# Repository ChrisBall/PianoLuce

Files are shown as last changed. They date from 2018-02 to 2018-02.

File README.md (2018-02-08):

# PianoLuce

PianoLuce is a keypress detector for pianos, based on the Arduino platform. This project is on hiatus, having achieved it's main aim, but others trying to achieve similar results may find these resources useful.

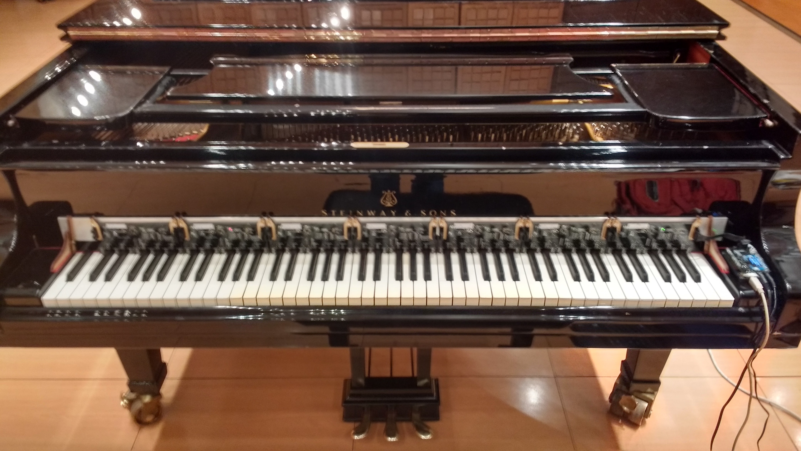
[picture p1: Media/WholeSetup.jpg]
PianoLuce in use


This project took inspiration from the development on the [Magnetic Resonator Piano](http://www.eecs.qmul.ac.uk/~andrewm/mrp.html) and similar, commercial keypress detectors like the Moog Piano Bar.

Most of the development was in aid of a performance by Marta Mołodyńska-Wheeler in June 2017, where live visuals were generated from her PhD performance of Scriabin's 24 preludes. The vision of the project was to re-create a modern day version of [Clavier à lumières](https://en.wikipedia.org/wiki/Clavier_%C3%A0_lumi%C3%A8res) by creating a non-intrusive device which could be attached to an expensive piano and create colored visuals.  Alex (Marta's husband), CEO of the IOT company [Kolomolo](www.kolomolo.com), connected with me during his research and commissioned the work.

My special thanks to: [Alex & Marta](http://www.martamolo.com/), for their time, patience, and escape rooms; to [James Medd](http://jamesmedd.co.uk/) for his assistance designing a mounting system, and coming up with the name, PianoLuce; and to [Alexander Lang](http://langster1980.blogspot.co.uk/), for his usual excellent support.

## Description

PianoLuce uses side-mounted IR reflection detectors to estimate the velocity of keypresses. An IR reflection sensor (QRE1113) above each key measures reflected IR light. These sensors are switched on and read in sequence by an ATMEGA328P via 16 channel 4067 analog multiplexers. Each PCB spans an octave (12 notes), and boards communicate via I2C, although SPI may be possible. A master controller is responsible for controlling calibration, receiving keypress data from each slave board, getting data from a sustain pedal, and sending midi over USB.

## Resources
- [Arduino Code](https://github.com/ChrisBall/PianoLuce/tree/master/Arduino)
- [Eagle Files](https://github.com/ChrisBall/PianoLuce/tree/master/Eagle)
- [Mount design and cad files](https://github.com/ChrisBall/PianoLuce/tree/master/SVG)
- [Other Media](https://github.com/ChrisBall/PianoLuce/tree/master/Media)

## Flaws and possible improvements

As mentioned, PianoLuce is only partially developed, and there are many factors to consider in an improved future version. Please bear these points in mind before using this project as a basis for your own.
- Currently, keypresses on black keys are detected with ambient IR, which is obviously highly variable. More reliable measurement can be made by adding white stickers to each black key, and altering the current code to light the appropriate IR LED. A simpler to install system may use two reflection sensors to sense the void left by the black key when it is pressed.
- I2C is not designed for long range transmission: although the current system works (multi-slave setup), it may be susceptible to noise, and there is significant latency introduced by evaluating 7 slave boards. Improved data transmission between master and slaves should be implemented.
- The electronic design, while functional, could be simplified, made cheaper and smaller, and use a faster microcontroller from the STM32 series.
- The 10 pin IDC connectors chosen for board interconnects may disturb the performance of experienced pianists, particularly those with smaller hands as they will use the full length of each key. A lower profile interconnect would be ideal.
- There is no visual feedback: this was intentional, as it was deemed undesirable for our purposes, but in most cases it should be an option. LED feedback for each key is simple to add.

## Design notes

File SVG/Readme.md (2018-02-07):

This folder contains files necessary to build an adjustable stand that will support multiple boards (but you may just wish to blu-tack them to your piano).

"Clips.svg" contains paths to laser-cut several clips from 3mm thick material, which attach to the slave PCBs with short M3 nuts & bolts. These clips will rest on a 50mm x 3mm x (required keyboard length) piece of aluminium. The clips have a small amount of adjustability.

"Stands.svg" contains paths to make a basic stand to hold the aforementioned piece of aluminium.

"Pedal sensor mount.svg" contains paths to cut a simple mount for sustain pedal sensor. We were using an IR reflection sensor board (ADDRESS) to sense the position of the pedal, but you may wish to use another solution.

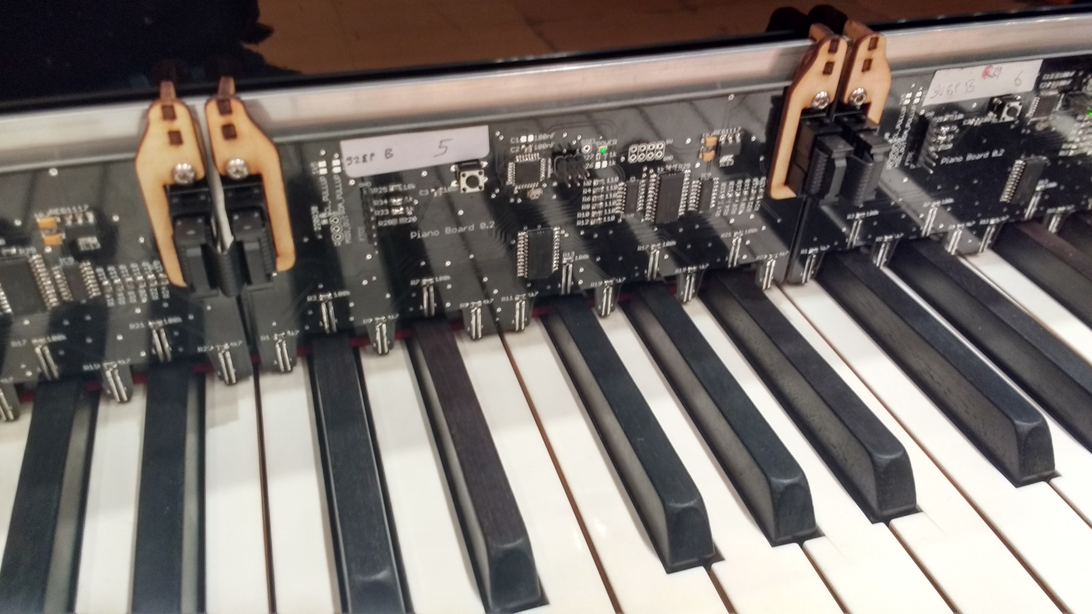
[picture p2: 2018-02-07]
Media/PianoLuce in place.jpg

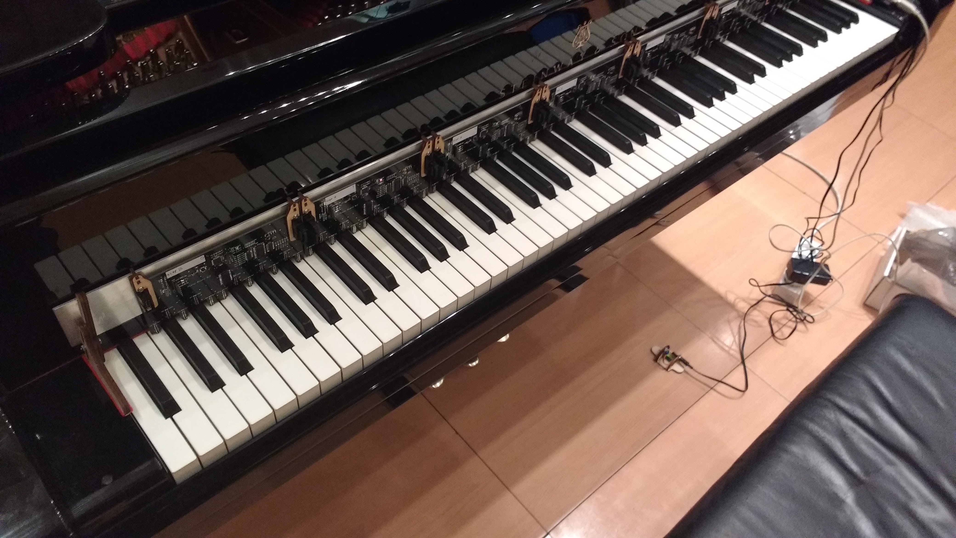
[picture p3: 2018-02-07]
Media/Slave & Master & Pedal Sensor.jpg

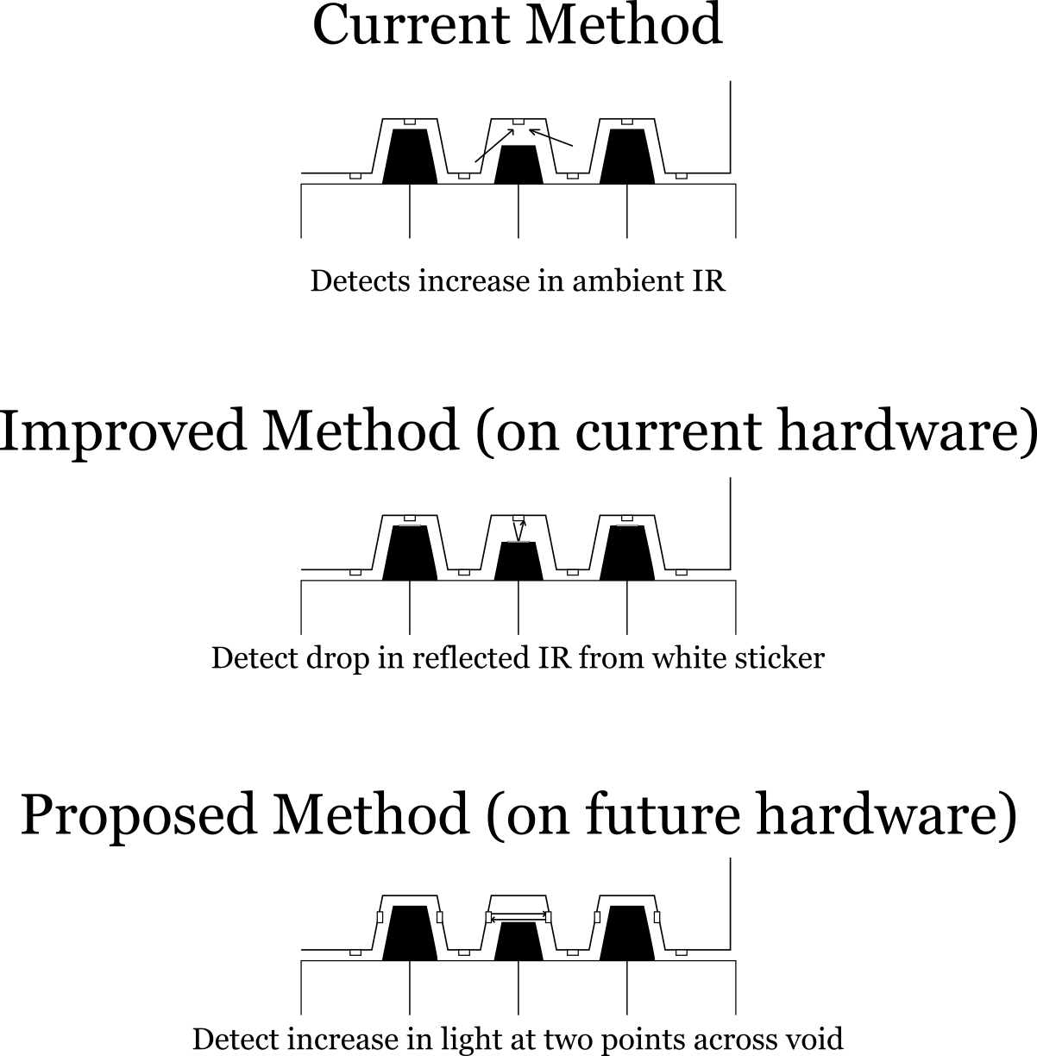
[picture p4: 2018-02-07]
Media/GH-sensing methods.png

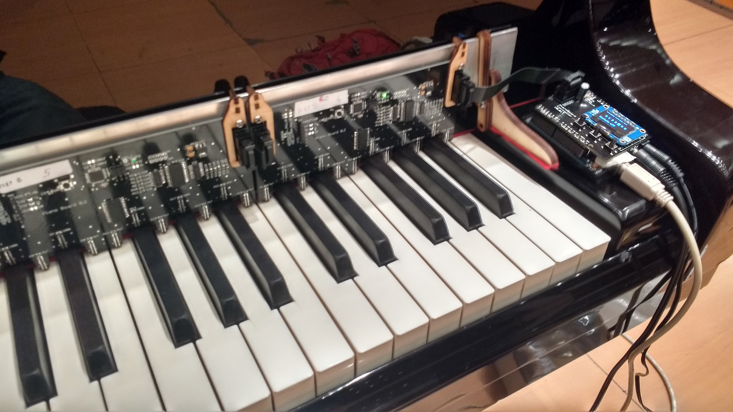
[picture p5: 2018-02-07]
Media/Slave & Master.jpg

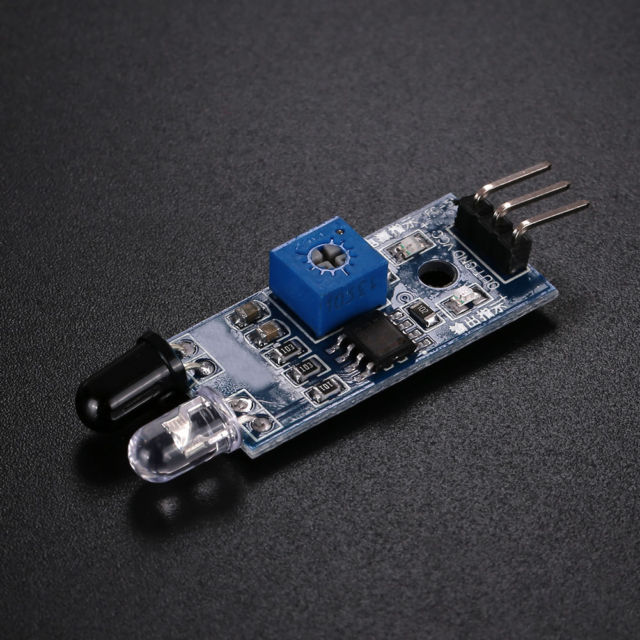
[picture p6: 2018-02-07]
Media/IR reflection.jpg

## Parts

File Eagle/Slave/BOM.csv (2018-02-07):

Qty | Value | Device | Package | Parts | Description | MF | MPN | OC_FARNELL | OC_NEWARK | PROD_ID | SPICEMODEL | SPICEPREFIX | VALUE
1 |  | LEDCHIPLED_0805 | CHIPLED_0805 | POWER | LED
1 |  | MA03-2 | MA03-2 | ICSP | PIN HEADER |  |  | unknown | unknown
1 |  | PINHD-1X1 | 1X01 | SSEL | Pin header 1x1 for 0.1 spacing"
1 |  | PINHD-1X3 | 1X03 | MIDI_OUT | PIN HEADER
1 |  | PINHD-1X6 | 1X06 | FTDI | PIN HEADER
1 |  | PINHD-2X4 | 2X04 | 5V | PIN HEADER
2 |  | PINHD-2X5IDC | 2X05IDC | IN, OUT | PIN HEADER
1 |  | SJ | SJ | SS_CONN | SMD solder JUMPER
5 | 100k | R-US_M0805 | M0805 | R3, R7, R13, R17, R21 | RESISTOR, American symbol
3 | 100nF | C | C0805 | C1, C2, C3 | CAPACITOR, European symbol |  |  |  |  |  | NONE | C
1 | 10k | R-US_M0805 | M0805 | R25 | RESISTOR, American symbol
2 | 10uF | CPOL-USSMCA | SMC_A | C5, C6 | POLARIZED CAPACITOR, American symbol
12 | 110 | R-US_M0805 | M0805 | R2, R4, R6, R8, R10, R12, R14, R16, R18, R20, R22, R24 | RESISTOR, American symbol
1 | 16MHZ | RESONATOR8MHZ | RESONATOR-SMD | Y1 | Resonator |  |  |  |  | XTAL-08895 |  |  | 8MHZ
5 | 1k | R-US_M0805 | M0805 | R26, R27, R29, R33, R34 | RESISTOR, American symbol
2 | 1k5 | R-US_M0805 | M0805 | SCL_PULLUP, SDA_PULLUP | RESISTOR, American symbol
2 | 220 | R-US_M0805 | M0805 | R28, R30 | RESISTOR, American symbol
2 | 4067D | 4067D | SO24W | IC3, IC4 | 16-channel ANALOG MULTIPLEXER
7 | 4k7 | R-US_M0805 | M0805 | R1, R5, R9, R11, R15, R19, R23 | RESISTOR, American symbol
1 | ATMEGA328P_TQFP | ATMEGA328P_TQFP | TQFP32-08 | U2 |  |  |  |  |  | IC-09069 |  |  | ATMEGA328P_TQFP
12 | QRE1113QRE1113 | QRE1113QRE1113 | QRE1113 | U$1, U$2, U$3, U$4, U$5, U$6, U$7, U$8, U$9, U$10, U$11, U$12
1 | REG1117 | REG1117 | SOT223 | IC13 | 800mA and 1A Low Dropout (LDO) Positive Regulator |  | REG1117 | 1097566 | 14P6981
1 | TACTILE-SWITCH-PTH | TACTILE-SWITCH-PTH | TAC-SWITCH-PTH | RESET | Tactile Switch 4 Pins, SPST NO
2 | ULN2001AD | ULN2001AD | SO16 | IC9, IC10 | DRIVER ARRAY

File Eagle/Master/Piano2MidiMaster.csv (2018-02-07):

Qty | Value | Device | Package | Parts | Description
1 |  | CPOL-USE2.5-6 | E2,5-6 | C1 | POLARIZED CAPACITOR, American symbol
2 |  | PINHD-1X2 | 1X02 | JP2, JP3 | PIN HEADER
1 |  | PINHD-1X8BIG | 1X08-BIG | JP1 | PIN HEADER
1 |  | PINHD-2X5IDC | 2X05IDC | OUT | PIN HEADER
1 |  | R-US_0207/12 | 0207/12 | SDA_PULLUP | RESISTOR, American symbol
1 |  | R-US_0207/15 | 0207/15 | SCL_PULLUP | RESISTOR, American symbol
1 | ARDUINOR3-DIMENSION | ARDUINOR3-DIMENSION | ARDUINOR3 | U1 | This is a new object for the new Arduino R3 - with extra pins that you may want to use (such as IOref, and duplicated A4/A5
1 | STEREOJACK | STEREOJACK | STX3100 | SUSTAIN | MIC/HEADPHONE JACK
3 | TACTILE-SWITCH-PTH | TACTILE-SWITCH-PTH | TAC-SWITCH-PTH | LEFT, RIGHT, SELECT | Tactile Switch 4 Pins, SPST NO

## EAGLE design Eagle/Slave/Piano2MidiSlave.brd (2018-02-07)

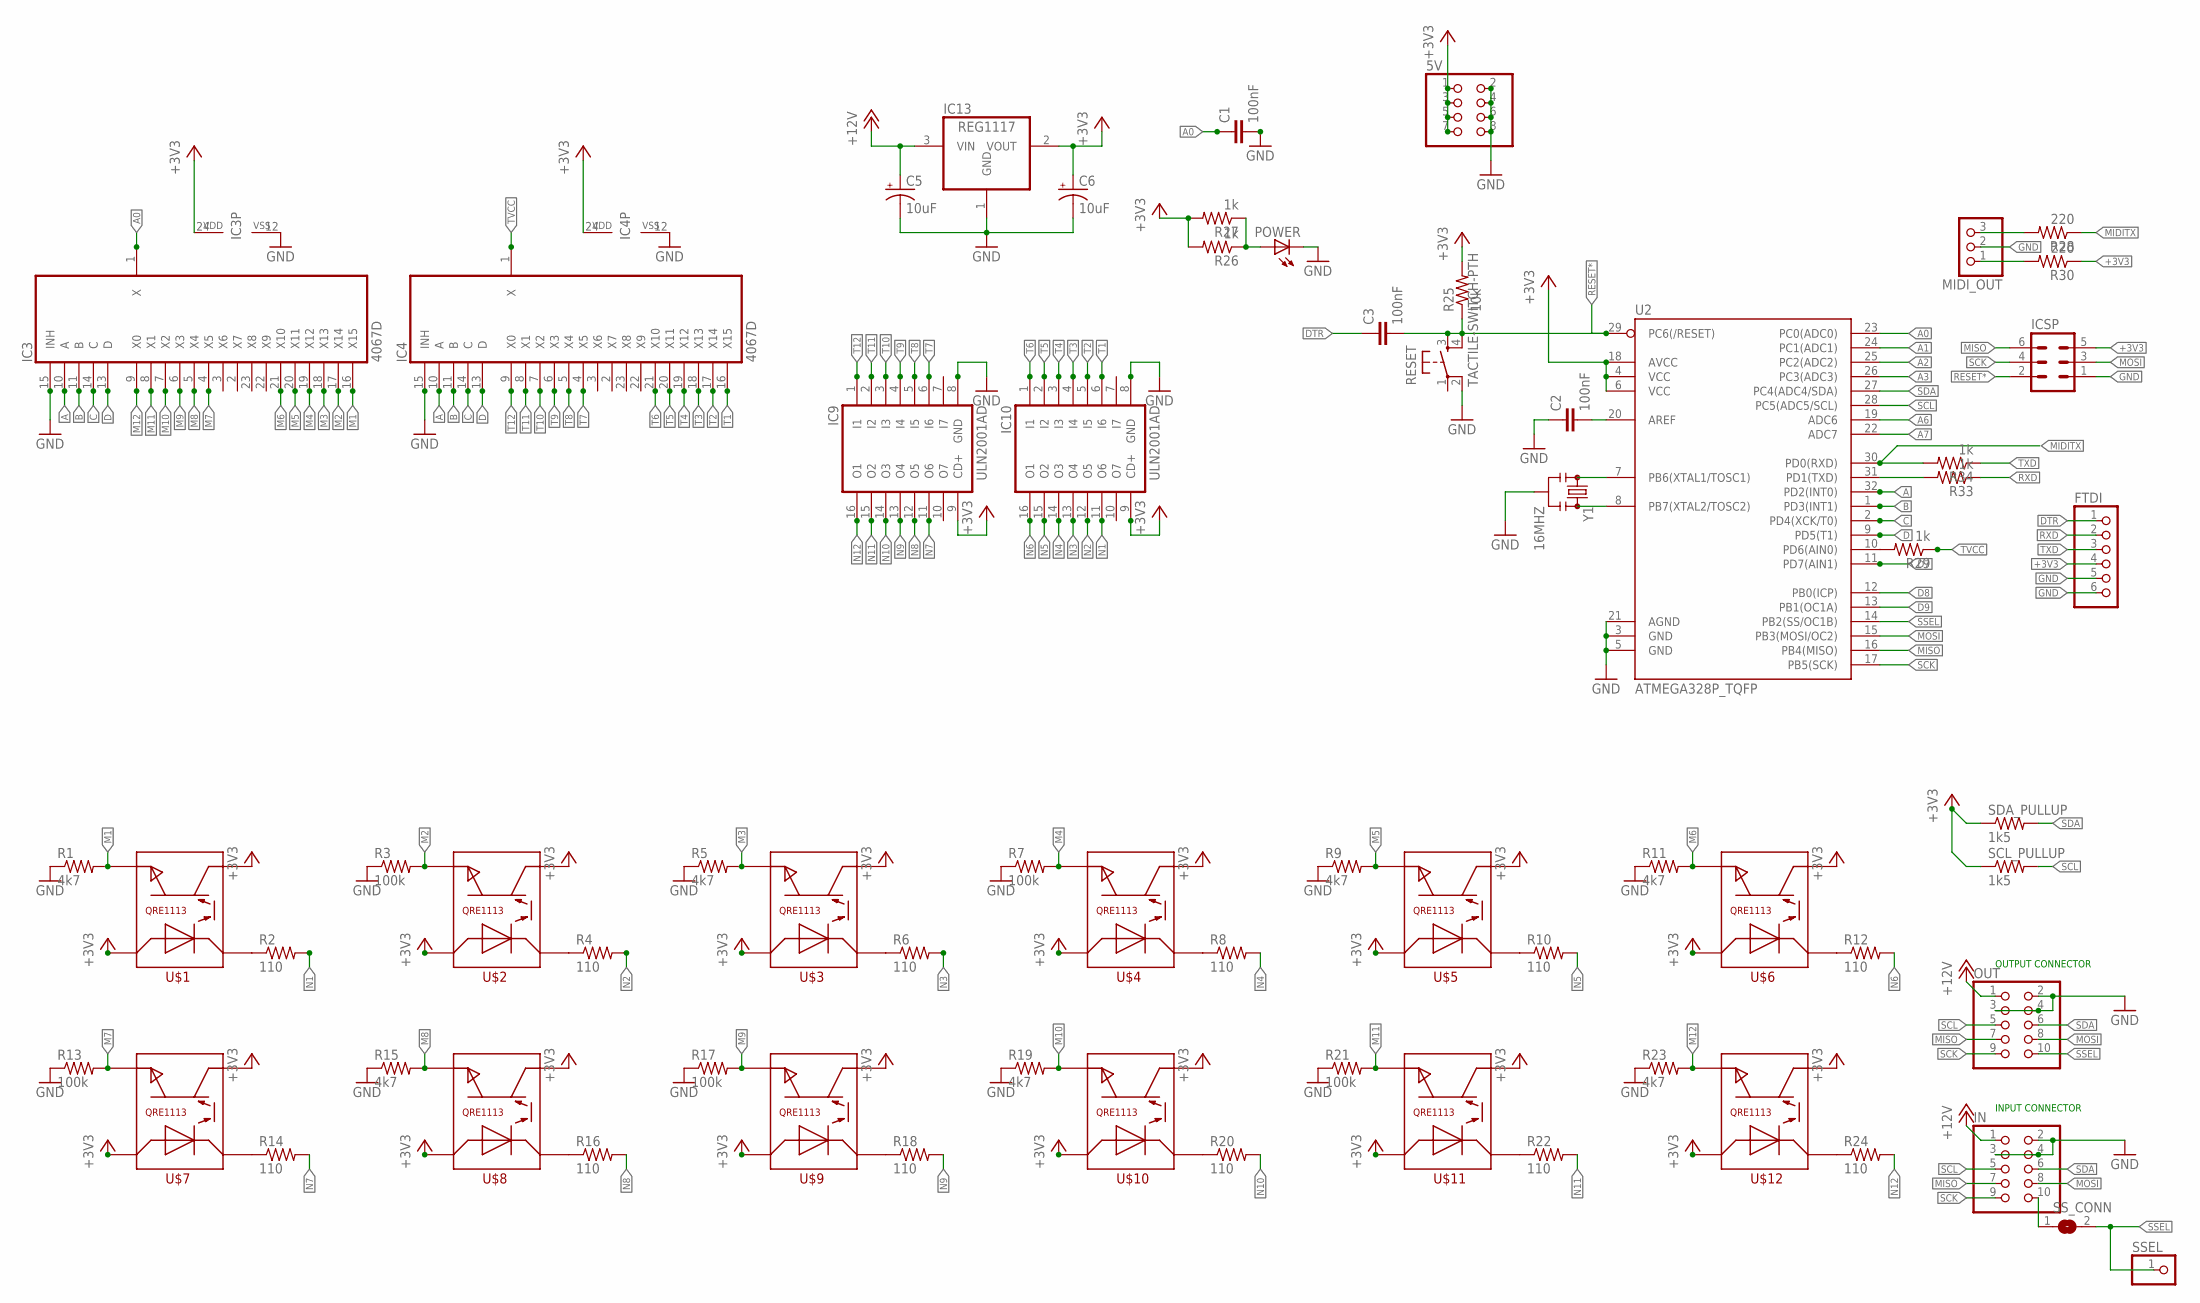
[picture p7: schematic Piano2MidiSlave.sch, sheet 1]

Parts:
5V: PINHD-2X4; 2X04
C1, C2, C3: 100nF; C0805
C5, C6: 10uF; SMC_A
FTDI: PINHD-1X6; 1X06
IC3, IC4: 4067D; SO24W
IC9, IC10: ULN2001AD; SO16
IC13: REG1117; SOT223
ICSP: MA03-2
IN: PINHD-2X5IDC; 2X05IDC
MIDI_OUT: PINHD-1X3; 1X03
OUT: PINHD-2X5IDC; 2X05IDC
POWER: LEDCHIPLED_0805; CHIPLED_0805
R1, R5, R9, R11, R15, R19, R23: 4k7; M0805
R2, R4, R6, R8, R10, R12, R14, R16, R18, R20, R22, R24: 110; M0805
R3, R7, R13, R17, R21: 100k; M0805
R25: 10k; M0805
R26, R27, R29, R33, R34: 1k; M0805
R28, R30: 220; M0805
RESET: TACTILE-SWITCH-PTH; TAC-SWITCH-PTH
SCL_PULLUP: 1k5; M0805
SDA_PULLUP: 1k5; M0805
SSEL: PINHD-1X1; 1X01
SS_CONN: SJ
U2: ATMEGA328P_TQFP; TQFP32-08
U$1, U$2, U$3, U$4, U$5, U$6, U$7, U$8, U$9, U$10, U$11, U$12: QRE1113QRE1113; QRE1113
Y1: 16MHZ; RESONATOR-SMD

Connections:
+3V3: 5V.1, 5V.3, 5V.5, 5V.7, C6.+, FTDI.4 (SDA), IC3.24 (VDD), IC4.24 (VDD), IC9.9 (CD+), IC10.9 (CD+), IC13.2 (VOUT), ICSP.5, R25.2, R26.2, R27.2, R30.1, SCL_PULLUP.1, SDA_PULLUP.1, U2.4 (VCC), U2.6 (VCC), U2.18 (AVCC), U$1.ANODE, U$1.COLLECTOR, U$2.ANODE, U$2.COLLECTOR, U$3.ANODE, U$3.COLLECTOR, U$4.ANODE, U$4.COLLECTOR, U$5.ANODE, U$5.COLLECTOR, U$6.ANODE, U$6.COLLECTOR, U$7.ANODE, U$7.COLLECTOR, U$8.ANODE, U$8.COLLECTOR, U$9.ANODE, U$9.COLLECTOR, U$10.ANODE, U$10.COLLECTOR, U$11.ANODE, U$11.COLLECTOR, U$12.ANODE, U$12.COLLECTOR
+12V: C5.+, IC13.3 (VIN), IN.1, OUT.1
A: IC3.10 (A), IC4.10 (A), U2.32 (PD2(INT0))
A0: C1.1, IC3.1 (X), U2.23 (PC0(ADC0))
A1: U2.24 (PC1(ADC1))
A2: U2.25 (PC2(ADC2))
A3: U2.26 (PC3(ADC3))
A6: U2.19 (ADC6)
A7: U2.22 (ADC7)
AREF: C2.2, U2.20 (AREF)
B: IC3.11 (B), IC4.11 (B), U2.1 (PD3(INT1))
C: IC3.14 (C), IC4.14 (C), U2.2 (PD4(XCK/T0))
D: IC3.13 (D), IC4.13 (D), U2.9 (PD5(T1))
D7: U2.11 (PD7(AIN1))
D8: U2.12 (PB0(ICP))
D9: U2.13 (PB1(OC1A))
DTR: C3.1, FTDI.1 (3V3)
GND: 5V.2, 5V.4, 5V.6, 5V.8, C1.2, C2.1, C5.-, C6.-, FTDI.5 (ADD), FTDI.6 (GND), IC3.12 (VSS), IC3.15 (INH), IC4.12 (VSS), IC4.15 (INH), IC9.8 (GND), IC10.8 (GND), IC13.1 (GND), ICSP.1, IN.2, IN.3, IN.4, MIDI_OUT.2, OUT.2, OUT.3, OUT.4, POWER.C, R1.1, R3.1, R5.1, R7.1, R9.1, R11.1, R13.1, R15.1, R17.1, R19.1, R21.1, R23.1, RESET.2, U2.3 (GND), U2.5 (GND), U2.21 (AGND), Y1.2
M1: IC3.16 (X15), R1.2, U$1.EMITTER
M2: IC3.17 (X14), R3.2, U$2.EMITTER
M3: IC3.18 (X13), R5.2, U$3.EMITTER
M4: IC3.19 (X12), R7.2, U$4.EMITTER
M5: IC3.20 (X11), R9.2, U$5.EMITTER
M6: IC3.21 (X10), R11.2, U$6.EMITTER
M7: IC3.4 (X5), R13.2, U$7.EMITTER
M8: IC3.5 (X4), R15.2, U$8.EMITTER
M9: IC3.6 (X3), R17.2, U$9.EMITTER
M10: IC3.7 (X2), R19.2, U$10.EMITTER
M11: IC3.8 (X1), R21.2, U$11.EMITTER
M12: IC3.9 (X0), R23.2, U$12.EMITTER
MIDITX: R28.1, R34.2, U2.30 (PD0(RXD))
MISO: ICSP.6, IN.7, OUT.7, U2.16 (PB4(MISO))
MOSI: ICSP.3, IN.8, OUT.8, U2.15 (PB3(MOSI/OC2))
N1: IC10.11 (O6), R2.2
N2: IC10.12 (O5), R4.2
N3: IC10.13 (O4), R6.2
N4: IC10.14 (O3), R8.2
N5: IC10.15 (O2), R10.2
N6: IC10.16 (O1), R12.2
N7: IC9.11 (O6), R14.2
N8: IC9.12 (O5), R16.2
N9: IC9.13 (O4), R18.2
N10: IC9.14 (O3), R20.2
N11: IC9.15 (O2), R22.2
N12: IC9.16 (O1), R24.2
unnamed: U2.8 (PB7(XTAL2/TOSC2)), Y1.3
unnamed: U2.7 (PB6(XTAL1/TOSC1)), Y1.1
unnamed: R4.1, U$2.CATHODE
unnamed: R6.1, U$3.CATHODE
unnamed: MIDI_OUT.3, R28.2
unnamed: R2.1, U$1.CATHODE
unnamed: POWER.A, R26.1, R27.1
unnamed: R8.1, U$4.CATHODE
unnamed: R29.2, U2.10 (PD6(AIN0))
unnamed: R10.1, U$5.CATHODE
unnamed: R12.1, U$6.CATHODE
unnamed: R24.1, U$12.CATHODE
unnamed: R33.2, U2.31 (PD1(TXD))
unnamed: R22.1, U$11.CATHODE
unnamed: R20.1, U$10.CATHODE
unnamed: R18.1, U$9.CATHODE
unnamed: R16.1, U$8.CATHODE
unnamed: R14.1, U$7.CATHODE
unnamed: IN.10, SS_CONN.1
unnamed: MIDI_OUT.1, R30.2
RESET*: C3.2, ICSP.2, R25.1, RESET.3, RESET.4, U2.29 (PC6(/RESET))
RXD: FTDI.2 (IRQ), R33.1
SCK: ICSP.4, IN.9, OUT.9, U2.17 (PB5(SCK))
SCL: IN.5, OUT.5, SCL_PULLUP.2, U2.28 (PC5(ADC5/SCL))
SDA: IN.6, OUT.6, SDA_PULLUP.2, U2.27 (PC4(ADC4/SDA))
SSEL: OUT.10, SSEL.1, SS_CONN.2, U2.14 (PB2(SS/OC1B))
T1: IC4.16 (X15), IC10.6 (I6)
T2: IC4.17 (X14), IC10.5 (I5)
T3: IC4.18 (X13), IC10.4 (I4)
T4: IC4.19 (X12), IC10.3 (I3)
T5: IC4.20 (X11), IC10.2 (I2)
T6: IC4.21 (X10), IC10.1 (I1)
T7: IC4.4 (X5), IC9.6 (I6)
T8: IC4.5 (X4), IC9.5 (I5)
T9: IC4.6 (X3), IC9.4 (I4)
T10: IC4.7 (X2), IC9.3 (I3)
T11: IC4.8 (X1), IC9.2 (I2)
T12: IC4.9 (X0), IC9.1 (I1)
TVCC: IC4.1 (X), R29.1
TXD: FTDI.3 (SCL), R34.1

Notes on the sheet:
INPUT CONNECTOR
OUTPUT CONNECTOR

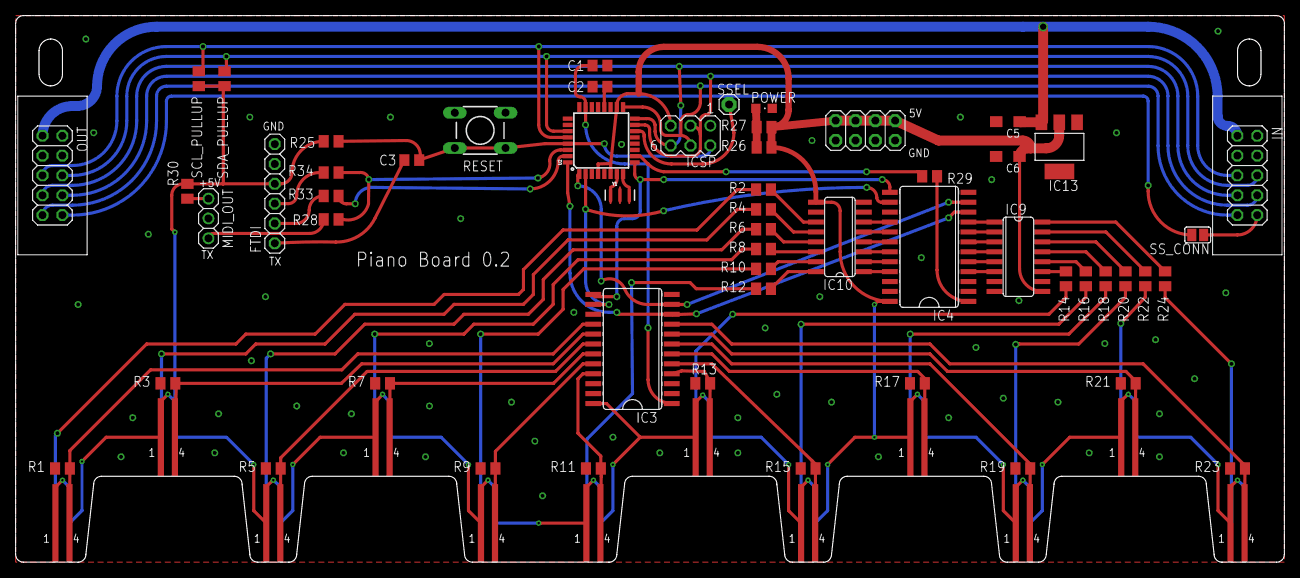
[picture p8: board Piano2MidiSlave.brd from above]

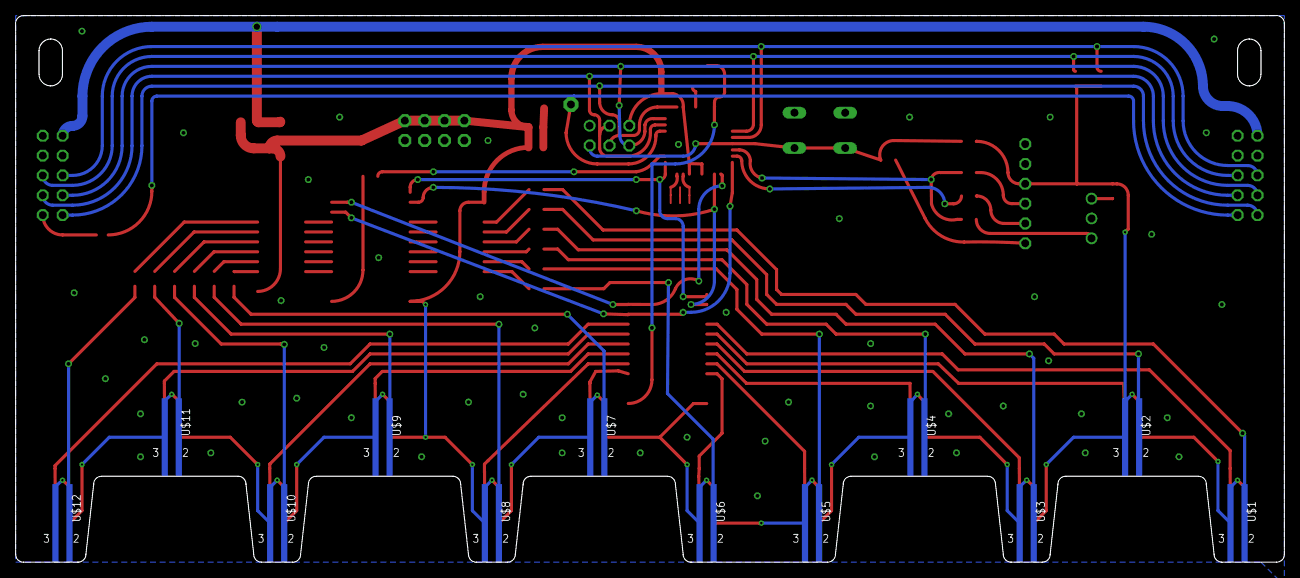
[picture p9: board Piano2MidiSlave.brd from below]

Board: 2 copper layers, 162.5 x 70.0 mm, 68 parts (12 on the bottom side), 77 nets.

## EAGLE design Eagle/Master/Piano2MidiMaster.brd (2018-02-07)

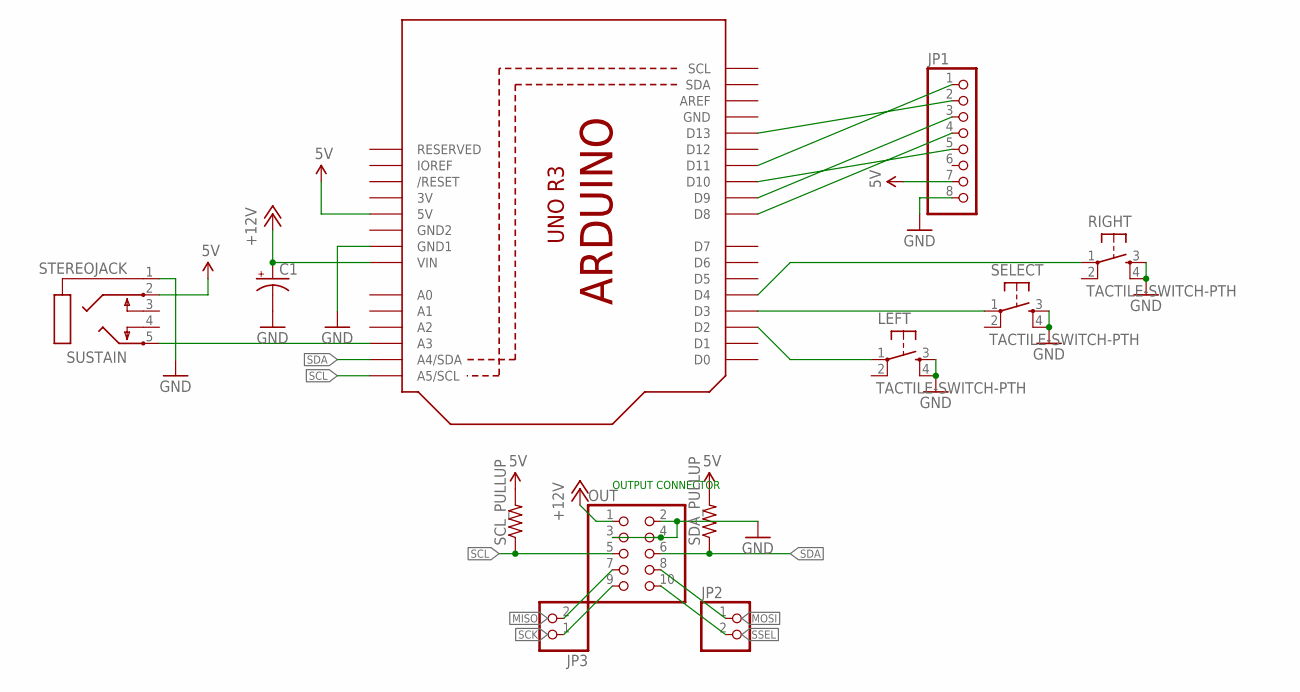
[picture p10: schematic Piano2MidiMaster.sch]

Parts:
C1: CPOL-USE2.5-6; E2,5-6
JP1: PINHD-1X8BIG; 1X08-BIG
JP2, JP3: PINHD-1X2; 1X02
LEFT: TACTILE-SWITCH-PTH; TAC-SWITCH-PTH
OUT: PINHD-2X5IDC; 2X05IDC
RIGHT: TACTILE-SWITCH-PTH; TAC-SWITCH-PTH
SCL_PULLUP: R-US_0207/15; 0207/15
SDA_PULLUP: R-US_0207/12; 0207/12
SELECT: TACTILE-SWITCH-PTH; TAC-SWITCH-PTH
SUSTAIN: STEREOJACK; STX3100
U1: ARDUINOR3-DIMENSION; ARDUINOR3

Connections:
3V: U1.3V
5V: JP1.7, SCL_PULLUP.2, SDA_PULLUP.2, SUSTAIN.2, U1.5V
+12V: C1.+, OUT.1, U1.VIN
GND: C1.-, JP1.8, LEFT.3, LEFT.4, OUT.2, OUT.3, OUT.4, RIGHT.3, RIGHT.4, SELECT.3, SELECT.4, SUSTAIN.1, U1.GND, U1.GND1
GND2: U1.GND2
MISO: JP3.2, OUT.7
MOSI: JP2.1, OUT.8
unnamed: JP1.1, U1.D11
unnamed: JP1.2, U1.D13
unnamed: JP1.3, U1.D9
unnamed: JP1.4, U1.D8
unnamed: JP1.5, U1.D10
unnamed: LEFT.1, U1.D2
unnamed: SELECT.1, U1.D3
unnamed: RIGHT.1, U1.D4
unnamed: SUSTAIN.5, U1.A3
SCK: JP3.1, OUT.9
SCL: OUT.5, SCL_PULLUP.1, U1.A5 (A5/SCL)
SDA: OUT.6, SDA_PULLUP.1, U1.A4 (A4/SDA)
SSEL: JP2.2, OUT.10

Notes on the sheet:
OUTPUT CONNECTOR

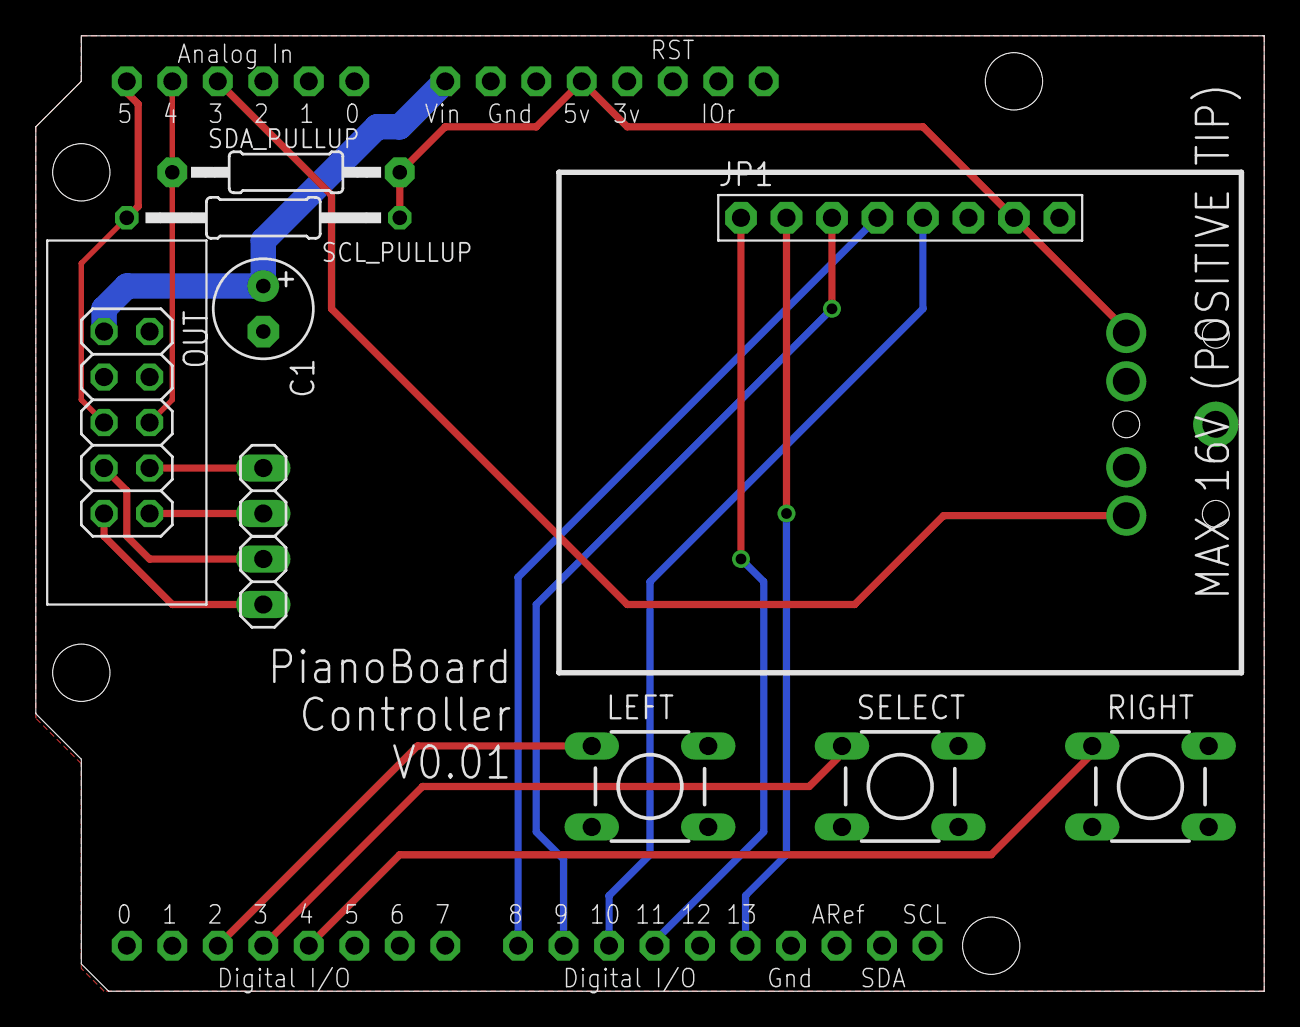
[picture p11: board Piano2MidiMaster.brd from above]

Board: 2 copper layers, 68.6 x 53.3 mm, 12 parts (1 on the bottom side), 18 nets.

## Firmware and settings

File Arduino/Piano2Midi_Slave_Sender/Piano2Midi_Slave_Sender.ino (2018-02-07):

//measures analog inputs and stores any triggers as 3 byte messages in FIFO array
//initially triggers are on/off, no velocity
//returns midi messages upon request from master

#include <QueueArray.h>  //for managing midi FIFO buffer
#include <Wire.h>        //for I2C
#include <TimerOne.h>    //for managing interrupt
#include <EEPROM.h>      //for storing calibration data


//CONFIG
#define ADDRESS 0
/* addresses are the octave the sensor is responsible for; 0=lowest, 8=highest.
   We are actually using 7 boards from C1 to B7 (we won't bother with A0,A#0,B0 & C8)
   1 = C1 to B1  = MIDI notes 24 to 35
   2 = C2 to B2  = MIDI notes 36 to 47
   3 = C3 to B3  = MIDI notes 48 to 59
   4 = C4 to B4  = MIDI notes 60 to 71
   5 = C5 to B5  = MIDI notes 72 to 83
   6 = C6 to B6  = MIDI notes 84 to 95
   7 = C7 to B7  = MIDI notes 96 to 107
*/

#define MIDIBUFFERSIZE 24
/* this is the size of the MIDI message buffer, where midi messages are temporarily
   stored until sending over I2C at an appropriate time. Default = TBC
*/

#define INTERRUPTPERIOD 1000 //1 milliseconds ~ 1000Hz. A 'fast' piano keypress is estimated to take 2.5ms
//see curves here: https://focusritedevelopmentteam.wordpress.com/2012/10/04/or-it-is-the-sound/

//END CONFIG

#define A 2    
#define B 3
#define C 4
#define D 5
#define TVCC 6    

// defines for setting and clearing register bits (for faster ADC)
#ifndef cbi
#define cbi(sfr, bit) (_SFR_BYTE(sfr) &= ~_BV(bit))
#endif
#ifndef sbi
#define sbi(sfr, bit) (_SFR_BYTE(sfr) |= _BV(bit))
#endif

const byte velocityLookup[100] = {
  127, 127, 127, 127, 108, 97, 89, 83, 78, 73,
  70, 66, 64, 61, 58, 56, 54, 52, 51, 49,
  47, 46, 44, 43, 42, 41, 39, 38, 37, 36,
  35, 34, 33, 32, 31, 31, 30, 29, 28, 27,
  27, 26, 25, 25, 24, 23, 23, 22, 21, 21,
  20, 20, 19, 19, 18, 18, 17, 16, 16, 16,
  15, 15, 14, 14, 13, 13, 12, 12, 11, 11,
  11, 10, 10, 9, 9, 9, 8, 8, 8, 7,
  7, 7, 6, 6, 5, 5, 5, 4, 4, 4,
  4, 3, 3, 3, 2, 2, 2, 1, 1
};
const byte muxPins[] = {15, 14, 13, 12, 11, 10, 5, 4, 3, 2, 1, 0}; //this will change on future boards
const byte pollOrder[] = {0, 6, 1, 7, 2, 8, 3, 9, 4, 10, 5, 11};
const boolean whiteKey[] = {1, 0, 1, 0, 1, 1, 0, 1, 0, 1, 0, 1};
const byte midiNote[] = {
  (ADDRESS + 2) * 12 + 0,
  (ADDRESS + 2) * 12 + 1,
  (ADDRESS + 2) * 12 + 2,
  (ADDRESS + 2) * 12 + 3,
  (ADDRESS + 2) * 12 + 4,
  (ADDRESS + 2) * 12 + 5,
  (ADDRESS + 2) * 12 + 6,
  (ADDRESS + 2) * 12 + 7,
  (ADDRESS + 2) * 12 + 8,
  (ADDRESS + 2) * 12 + 9,
  (ADDRESS + 2) * 12 + 10,
  (ADDRESS + 2) * 12 + 11
};

int sensorReading[12] = {0};

//used during calibration
boolean calibrateSensors = false;
int maxSensorReading[12] = {0, 0, 0, 0, 0, 0, 0, 0, 0, 0, 0, 0};
int minSensorReading[12] = {1023, 1023, 1023, 1023, 1023, 1023, 1023, 1023, 1023, 1023, 1023, 1023};
int uThreshold[12] = {511, 511, 511, 511, 511, 511, 511, 511, 511, 511, 511, 511};
int lThreshold[12] = {511, 511, 511, 511, 511, 511, 511, 511, 511, 511, 511, 511};
byte noteTimer[12] = {0, 0, 0, 0, 0, 0, 0, 0, 0, 0, 0, 0};

boolean noteStates[12] = {0};

struct midiMessage {
  byte type;
  byte val1;
  byte val2;
};

QueueArray <midiMessage> midiBuffer;

void setup() {
  delay(50 + ADDRESS * 50);                 // wait for master and lower numbered slaves to become established, then...
  Wire.begin(ADDRESS);                      // join i2c bus with chosen address
  Wire.setClock(400000L);                   // comment if failure at high rates
  Wire.onRequest(requestEvent);             // register event
  Wire.onReceive(receiveEvent);             // register event (for calibration)
  Timer1.initialize(INTERRUPTPERIOD);       //delay time between sensor sweeps (1ms)
  Timer1.attachInterrupt(pollSensors);
  Serial.begin(115200);                     //serial for debugging
  //set up pins
  for (int i = 2; i < 7; i++) {
    pinMode(i, OUTPUT);  //mux A,B,C,D and TVCC (voltage supply for the output LED mux)
  }
  digitalWrite(TVCC, LOW);
  loadCalibration();  //loads calibration data from EEPROM

  // set prescale to 8 (9uS per analogRead)
  // cbi(ADCSRA,ADPS2) ;
  // sbi(ADCSRA,ADPS1) ;
  // sbi(ADCSRA,ADPS0) ;
  // set prescale to 16 (16uS per analogRead)
  sbi(ADCSRA, ADPS2) ;
  cbi(ADCSRA, ADPS1) ;
  cbi(ADCSRA, ADPS0) ;
}

void loop() {
  if (Serial) {
    printSensorData();
  }
}

// function that executes whenever data is requested by master
// this function is registered as an event, see setup()
void requestEvent() {
  if (!midiBuffer.isEmpty()) {
    midiMessage MM = midiBuffer.dequeue();  //is this unnecessary?
    byte midiOut[] = {MM.type, MM.val1, MM.val2};                     //can reduce this to two bytes. one has the note value 0-127 and the on/off bit, the other has the velocity
    Wire.write(midiOut, 3);
  } else {
    Wire.write(0); //meaning we have no data
    Wire.write(0);
    Wire.write(0);
  }
}

void receiveEvent(int howMany) {
  while (Wire.available()) { // loop through all but the last
    char type = Wire.read(); // receive byte as a character
    if (type == 'c') {    //"calibrate"
      for (int i = 0; i < 12; i++) {
        maxSensorReading[i] = 0;
        minSensorReading[i] = 1023;
        uThreshold[i] = 511;
        lThreshold[i] = 511;
      }
      calibrateSensors = true;
    } else if (type == 'e') {  //"end calibrate"
      calibrateSensors = false;
      saveCalibration();  //save calibration data to EEPROM
    }
  }
}

void loadCalibration() {
  noInterrupts();
  //load calibration data from eeprom
  for (int i = 0; i < 12; i++) {
    lThreshold[i] = EEPROM.read(i) << 2;      //lower thresholds stored in EEPROM addresses 0-11
  }
  for (int i = 0; i < 12; i++) {
    uThreshold[i] = EEPROM.read(i + 12) << 2; //upper thresholds stored in EEPROM addresses 12-23
  }
  interrupts();
}

void saveCalibration() {
  noInterrupts();
  //save calibration data to EEPROM - we lose a couple of bits accuracy in the process
  for (int i = 0; i < 12; i++) {
    EEPROM.write(i, lThreshold[i] >> 2);      //lower thresholds stored in EEPROM addresses 0-11
  }
  for (int i = 0; i < 12; i++) {
    EEPROM.write(i + 12, uThreshold[i] >> 2); //upper thresholds stored in EEPROM addresses 12-23
  }
  interrupts();
}

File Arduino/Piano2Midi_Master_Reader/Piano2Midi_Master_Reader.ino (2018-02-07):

#include <Wire.h>   //for I2C devices
#include "U8glib.h"  //for display

#define LEFT 0
#define SELECT 1
#define RIGHT 2

U8GLIB_SSD1306_ADAFRUIT_128X64 u8g(10, 9); //start display with serial SPI

boolean midiMode = true;  //choose midi or human-readable output
boolean hairless = true;   //if sending midi, USB format or hairless?
const byte minBoard = 0;
const byte maxBoard = 6;

boolean noteStates[128] = {0};
boolean enabled[7] = {1, 1, 1, 1, 1, 1, 1};
boolean calibrating[7] = {0, 0, 0, 0, 0, 0, 0};

byte buttonPins[] = {2, 3, 4};
byte buttonStates[] = {0, 0, 0};
byte sustainPin = A3;
byte sustainState = 0;

void setup() {
  Wire.begin();        // join i2c bus (address optional for master)
  Wire.setClock(400000L);  //400kHz speed

  pinMode(8, OUTPUT); //OLED reset pin
  digitalWrite(8, LOW); //reset the OLED
  delay(10);
  digitalWrite(8, HIGH);
  u8g.setColorIndex(1);  //set mode to BW
  u8g.begin();

  Serial.begin(115200);  // start serial for output
  //Serial.println("Piano2Midi Controller V0.1");
  for (int i = 0; i < 3; i++) {
    pinMode(buttonPins[i], INPUT_PULLUP);
  }
  pinMode(sustainPin, INPUT_PULLUP);
}

void loop() {
  buttonUpdate();       //updates button states
  buttonActions();      //updates what they do
  updateDisplay();      //updates the display
  getMessages();        //checks for any MIDI notes over I2C, and sends them as midi messages
  updateSustain(); //check whether sustain is on/off and send midi accordingly. Audio jack: tip-A3, mid-5V, collar-GND
}


//compatible with USB MIDI firmware
void midiMessage(int commandByte, int channelByte, int data1Byte, int data2Byte) {
  if (midiMode) {
    Serial.write(commandByte);
    if (!hairless) {
      Serial.write(channelByte);
    }
    Serial.write(data1Byte);
    Serial.write(data2Byte);
  } else {
    Serial.print(commandByte); Serial.print("\t");
    Serial.print(data1Byte); Serial.print("\t");
    Serial.println(data2Byte);
  }
}

void beginCalibration(byte BOARD) {
  Wire.beginTransmission(BOARD); // transmit to device #BOARD
  Wire.write('c');               //send 'c' char to begin calibration on selected board
  Wire.endTransmission();    // stop transmitting
}
void endCalibration(byte BOARD) {
  Wire.beginTransmission(BOARD); // transmit to device #BOARD
  Wire.write('e');               //send 'c' char to begin calibration on selected board
  Wire.endTransmission();    // stop transmitting
}

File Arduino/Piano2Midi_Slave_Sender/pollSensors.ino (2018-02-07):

/*function that executes every 1ms (?TBC?) to read sensor data.
   we do not switch on the LED (TVCC) on black keys, instead relying on reflected light from the white keys/ambient light (this is a bad idea).
   This inverts the response on the black keys, which will be low->high, instead of high->low.
*/

void pollSensors() {
  for (int i = 0; i < 12; i++) {
    byte pin = pollOrder[i];

    //set multiplexer bits
    if (whiteKey[pin]) {
      PORTD = (muxPins[pin] << 2) + 64; //this line writes the multiplexer bits (muxPins[pin]<<2) and the TVCC bit (+64)
    } else {
      PORTD = (muxPins[pin] << 2);   //we don't write the TVCC bit for black keys - we leave the output IR LED off
    }

    //wait for LED to rise (and previous to fall) - this is not perfect and there is always residual light.
    delayMicroseconds(40);

    //get reading
    sensorReading[pin] = analogRead(A0);

    //work out new thresholds if we're calibrating
    if (calibrateSensors) {
      minSensorReading[pin] = min(minSensorReading[pin], sensorReading[pin]);
      maxSensorReading[pin] = max(maxSensorReading[pin], sensorReading[pin]);
      uThreshold[pin] = minSensorReading[pin] + (((maxSensorReading[pin] - minSensorReading[pin]) * 5) >> 3);
      lThreshold[pin] = minSensorReading[pin] + (((maxSensorReading[pin] - minSensorReading[pin]) * 3) >> 3);
    }

    if ((sensorReading[pin] <= uThreshold[pin]) && (sensorReading[pin] >= lThreshold[pin]) ) { //if between thresholds, add to the timer
      if (noteTimer[pin] < 99) {
        noteTimer[pin]++;
      }
    }

    //basic triggering; note On:
    if ((sensorReading[pin] < lThreshold[pin]) && (!noteStates[pin])) {
      noteStates[pin] = true;
      midiMessage noteEvent;
      if (whiteKey[pin]) {
        sendMessage(0x90, midiNote[pin], velocityLookup[noteTimer[pin]]); //Note on
      } else {
        sendMessage(0x80, midiNote[pin], 100); //Note off
      }
      noteTimer[pin] = 0;
    }

    //basic triggering; note Off:
    if ((sensorReading[pin] > uThreshold[pin]) && (noteStates[pin])) {
      noteStates[pin] = false;
      midiMessage noteEvent;
      if (whiteKey[pin]) {
        sendMessage(0x80, midiNote[pin], 100); //Note off
      } else {
        noteTimer[pin] = constrain(noteTimer[pin] * 2, 0, 99);
        sendMessage(0x90, midiNote[pin], velocityLookup[noteTimer[pin]]); //Note on
      }
      noteTimer[pin] = 0;
    }

    if (sensorReading[pin] < lThreshold[pin]) {
      noteTimer[pin] = 0;
    }
  }
}


void sendMessage(byte type, byte val1, byte val2) {
  midiMessage noteEvent;
  noteEvent.type = type;
  noteEvent.val1 = val1;
  noteEvent.val2 = val2;
  if (midiBuffer.count() < MIDIBUFFERSIZE) {
    midiBuffer.push(noteEvent);
  }
}

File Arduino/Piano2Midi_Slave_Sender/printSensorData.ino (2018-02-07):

void printSensorData() {
//  for (int i = 0; i < 12; i++) {
//    Serial.print(sensorAnalogReadings[i]);
//    Serial.print("\t");
//  }
//  Serial.println();
  byte sensor=6;
  Serial.print(sensorReading[sensor]);
  Serial.print("\t");
  Serial.print(minSensorReading[sensor]);
  Serial.print("\t");
  Serial.print(maxSensorReading[sensor]);
  Serial.print("\t");
  Serial.print(uThreshold[sensor]);
  Serial.print("\t");
  Serial.print(lThreshold[sensor]);
  Serial.print("\t");
  Serial.print(noteTimer[sensor]);
  Serial.print("\t");
  
  if (!midiBuffer.isEmpty()) {
    midiMessage sneaky=midiBuffer.peek();
    Serial.print(midiBuffer.count());
  }
  
  Serial.println();
}

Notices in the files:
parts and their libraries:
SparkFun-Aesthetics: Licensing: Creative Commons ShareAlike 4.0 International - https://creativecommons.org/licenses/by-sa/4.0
